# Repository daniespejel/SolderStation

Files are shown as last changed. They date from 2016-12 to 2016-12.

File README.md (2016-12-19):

# Solderstation

Barebones Atmega328 based Soldering station  
Firmware: https://github.com/fngstudios/SolderStation_Software

## Features  
*FTDI/Arduino programming port     
*Common soldering tip (with thermocouple) compatible  
*Uses MAX31856 for TC reading  
*Configurable TC type supports J,K,N,E,etc  
*Configurable LCD contrast  
*PID control Kp,Ki and Kd configurable via UI  
*Idle mode for longer tip life  
*Automatic switch-off  
*Arduino compatible 100% customizable  
*Uses any PSU up to 35v like common laptop PSUs (depends on your tip)  
*Can be used barebones (with no cabinet) or built inside custom cabinet  

## Images

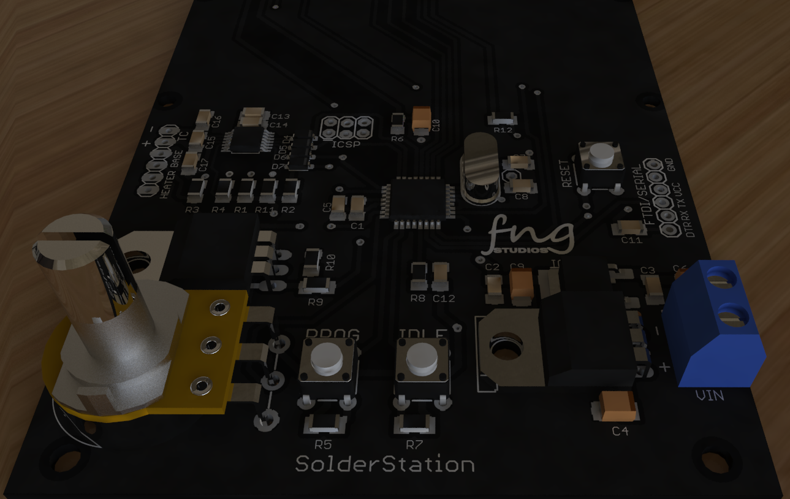
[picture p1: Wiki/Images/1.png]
  
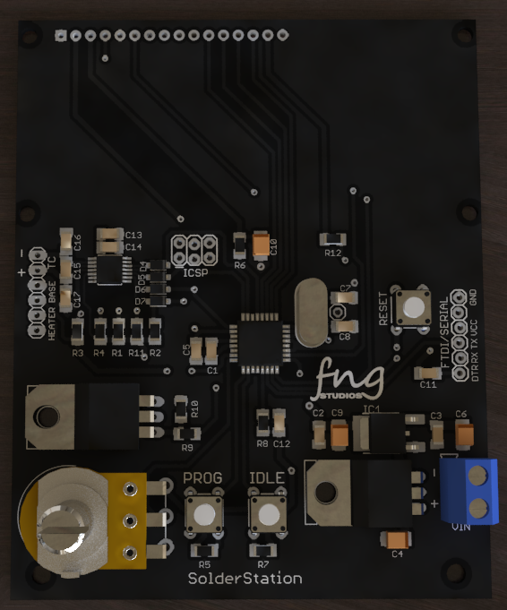
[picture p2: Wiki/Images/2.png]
  
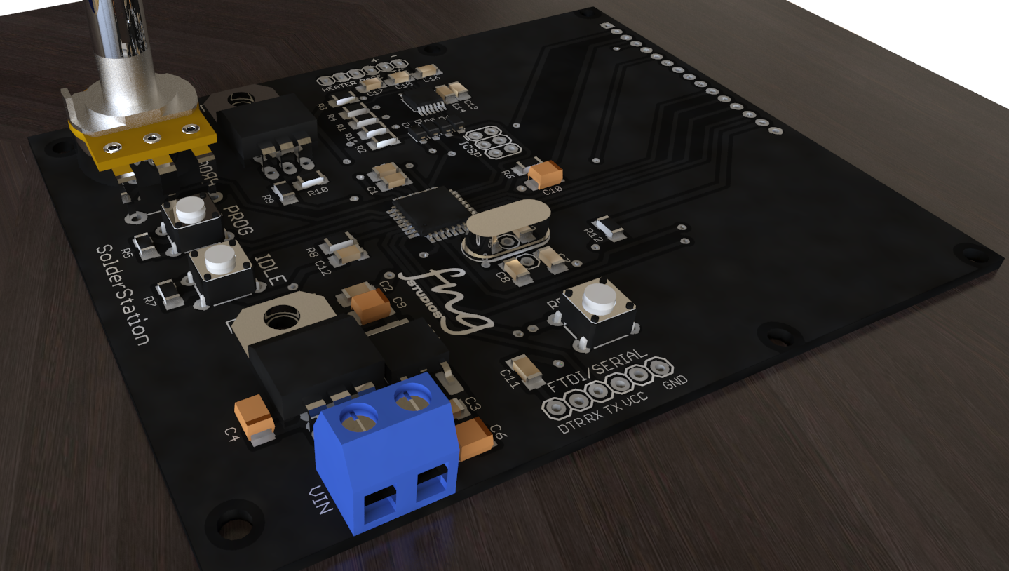
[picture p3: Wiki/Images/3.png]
  
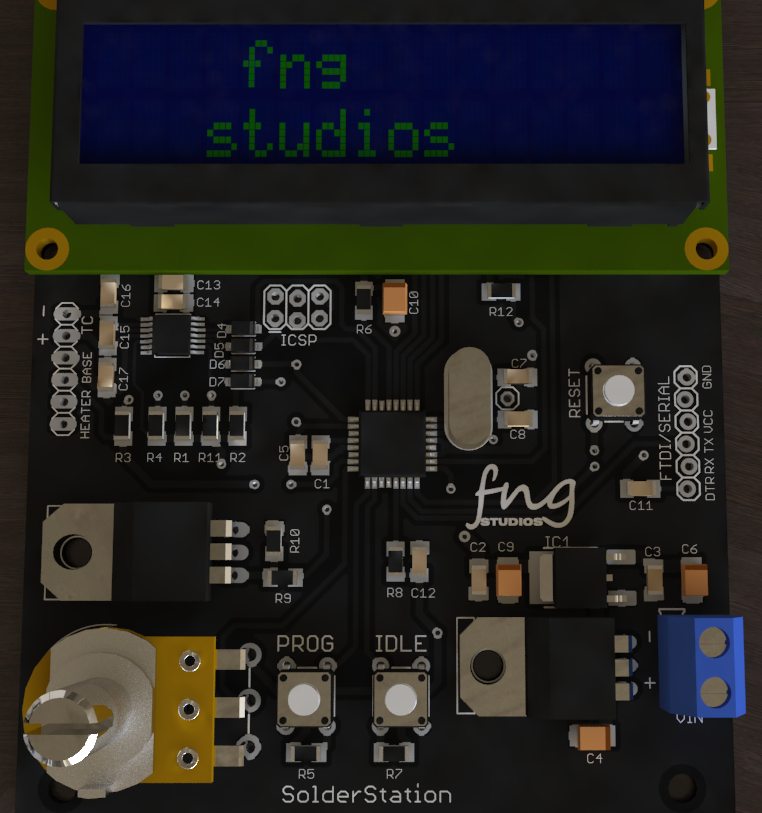
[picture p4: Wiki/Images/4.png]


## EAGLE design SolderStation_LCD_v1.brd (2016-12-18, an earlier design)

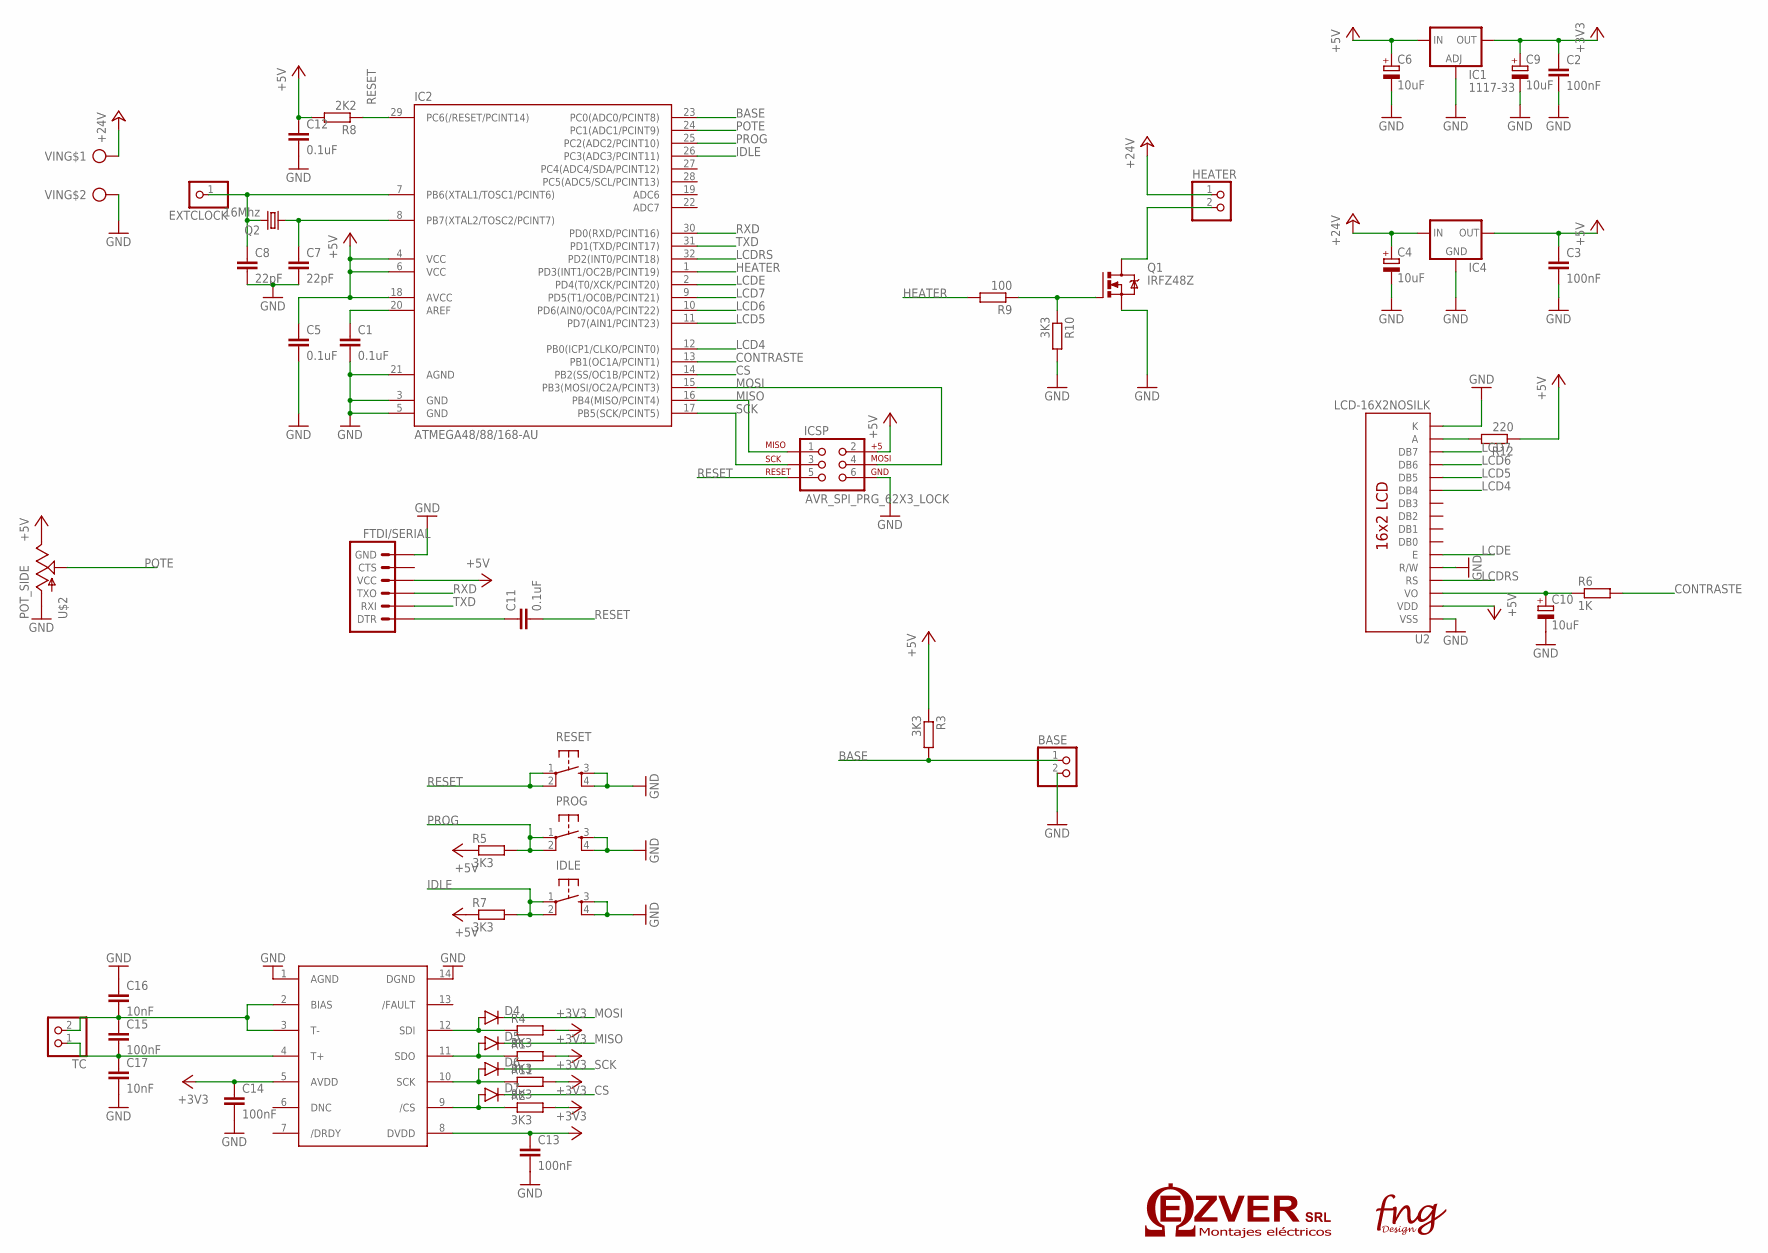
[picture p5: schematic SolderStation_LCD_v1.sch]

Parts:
BASE: PINHD-1X2; 1X02
C1, C5, C11, C12: 0.1uF; C1206K
C2, C3, C13, C14, C15: 100nF; C1206K
C4, C6, C9, C10: 10uF; CT3528
C7, C8: 22pF; C1206K
C16, C17: 10nF; C1206K
D4, D5, D6, D7: DIODESOD123; SOD-123
EXTCLOCK: PINHD-1X1; 1X01
FTDI/SERIAL: ARDUINO_SERIAL_PROGRAMLOCK; 1X06_LOCK
HEATER: PINHD-1X2; 1X02
IC1: 1117-33; DPACK
IC2: ATMEGA48/88/168-AU; TQFP32-08
IC4: 78XXL
ICSP: AVR_SPI_PRG_62X3_LOCK; 2X3_LOCK
IDLE: TAC_SWITCHPTH; TACTILE-PTH
PROG: TAC_SWITCHPTH; TACTILE-PTH
Q1: IRFZ48Z; TO220BH
Q2: 16Mhz; HC49U70
R1, R2, R3, R4, R5, R7, R10, R11: 3K3; M1206
R6: 1K; M1206
R8: 2K2; M1206
R9: 100; M1206
R12: 220; M1206
RESET: TAC_SWITCHPTH; TACTILE-PTH
TC: PINHD-1X2; 1X02
TC1: MAX31856; TSSOP-14
U2: LCD-16X2NOSILK; LCD-16X2_NOSILK
U$2: POT_SIDE; POT_ALPHA_SIDE
VIN: CON2

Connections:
+3V3: C2.1, C9.+, C13.1, C14.1, IC1.4 (OUT), R1.2, R2.2, R4.2, R11.2, TC1.5 (AVDD), TC1.8 (DVDD)
+5V: C3.1, C5.1, C6.+, C12.1, FTDI/SERIAL.4 (VCC), IC1.3 (IN), IC2.4 (VCC), IC2.6 (VCC), IC2.18 (AVCC), IC4.OUT, ICSP.2, R3.1, R5.1, R7.1, R8.2, R12.1, U2.2 (VDD), U$2.3 (E)
+24V: C4.+, HEATER.1, IC4.IN, VIN.1
BASE: BASE.1, IC2.23 (PC0(ADC0/PCINT8)), R3.2
CONTRASTE: IC2.13 (PB1(OC1A/PCINT1)), R6.2
CS: D7.C, IC2.14 (PB2(SS/OC1B/PCINT2))
GND: BASE.2, C1.2, C2.2, C3.2, C4.-, C5.2, C6.-, C7.2, C8.2, C9.-, C10.-, C12.2, C13.2, C14.2, C16.1, C17.2, FTDI/SERIAL.6 (GND), IC1.1 (ADJ), IC2.3 (GND), IC2.5 (GND), IC2.21 (AGND), IC4.GND, ICSP.6, IDLE.3, IDLE.4, PROG.3, PROG.4, Q1.S, R10.2, RESET.3, RESET.4, TC1.1 (AGND), TC1.14 (DGND), U2.1 (VSS), U2.5 (R/W), U2.16 (K), U$2.1 (A), VIN.2
HEATER: IC2.1 (PD3(INT1/OC2B/PCINT19)), R9.2
IDLE: IC2.26 (PC3(ADC3/PCINT11)), IDLE.1, IDLE.2, R7.2
LCD4: IC2.12 (PB0(ICP1/CLKO/PCINT0)), U2.11 (DB4)
LCD5: IC2.11 (PD7(AIN1/PCINT23)), U2.12 (DB5)
LCD6: IC2.10 (PD6(AIN0/OC0A/PCINT22)), U2.13 (DB6)
LCD7: IC2.9 (PD5(T1/OC0B/PCINT21)), U2.14 (DB7)
LCDE: IC2.2 (PD4(T0/XCK/PCINT20)), U2.6 (E)
LCDRS: IC2.32 (PD2(INT0/PCINT18)), U2.4 (RS)
MISO: D5.C, IC2.16 (PB4(MISO/PCINT4)), ICSP.1
MOSI: D4.C, IC2.15 (PB3(MOSI/OC2A/PCINT3)), ICSP.4
unnamed: Q1.G, R9.1, R10.1
unnamed: D7.A, R2.1, TC1.9 (/CS)
unnamed: D6.A, R11.1, TC1.10 (SCK)
unnamed: D5.A, R1.1, TC1.11 (SDO)
unnamed: HEATER.2, Q1.D
unnamed: D4.A, R4.1, TC1.12 (SDI)
unnamed: C7.1, IC2.8 (PB7(XTAL2/TOSC2/PCINT7)), Q2.1
unnamed: C10.+, R6.1, U2.3 (VO)
unnamed: C8.1, EXTCLOCK.1, IC2.7 (PB6(XTAL1/TOSC1/PCINT6)), Q2.2
unnamed: C1.1, IC2.20 (AREF)
unnamed: R12.2, U2.15 (A)
unnamed: C11.1, FTDI/SERIAL.1 (DTR)
unnamed: C15.2, C17.1, TC.1, TC1.4 (T+)
unnamed: C15.1, C16.2, TC.2, TC1.2 (BIAS), TC1.3 (T-)
POTE: IC2.24 (PC1(ADC1/PCINT9)), U$2.2 (S)
PROG: IC2.25 (PC2(ADC2/PCINT10)), PROG.1, PROG.2, R5.2
RESET: C11.2, IC2.29 (PC6(/RESET/PCINT14)), ICSP.5, R8.1, RESET.1, RESET.2
RXD: FTDI/SERIAL.3 (TXO), IC2.30 (PD0(RXD/PCINT16))
SCK: D6.C, IC2.17 (PB5(SCK/PCINT5)), ICSP.3
TXD: FTDI/SERIAL.2 (RXI), IC2.31 (PD1(TXD/PCINT17))

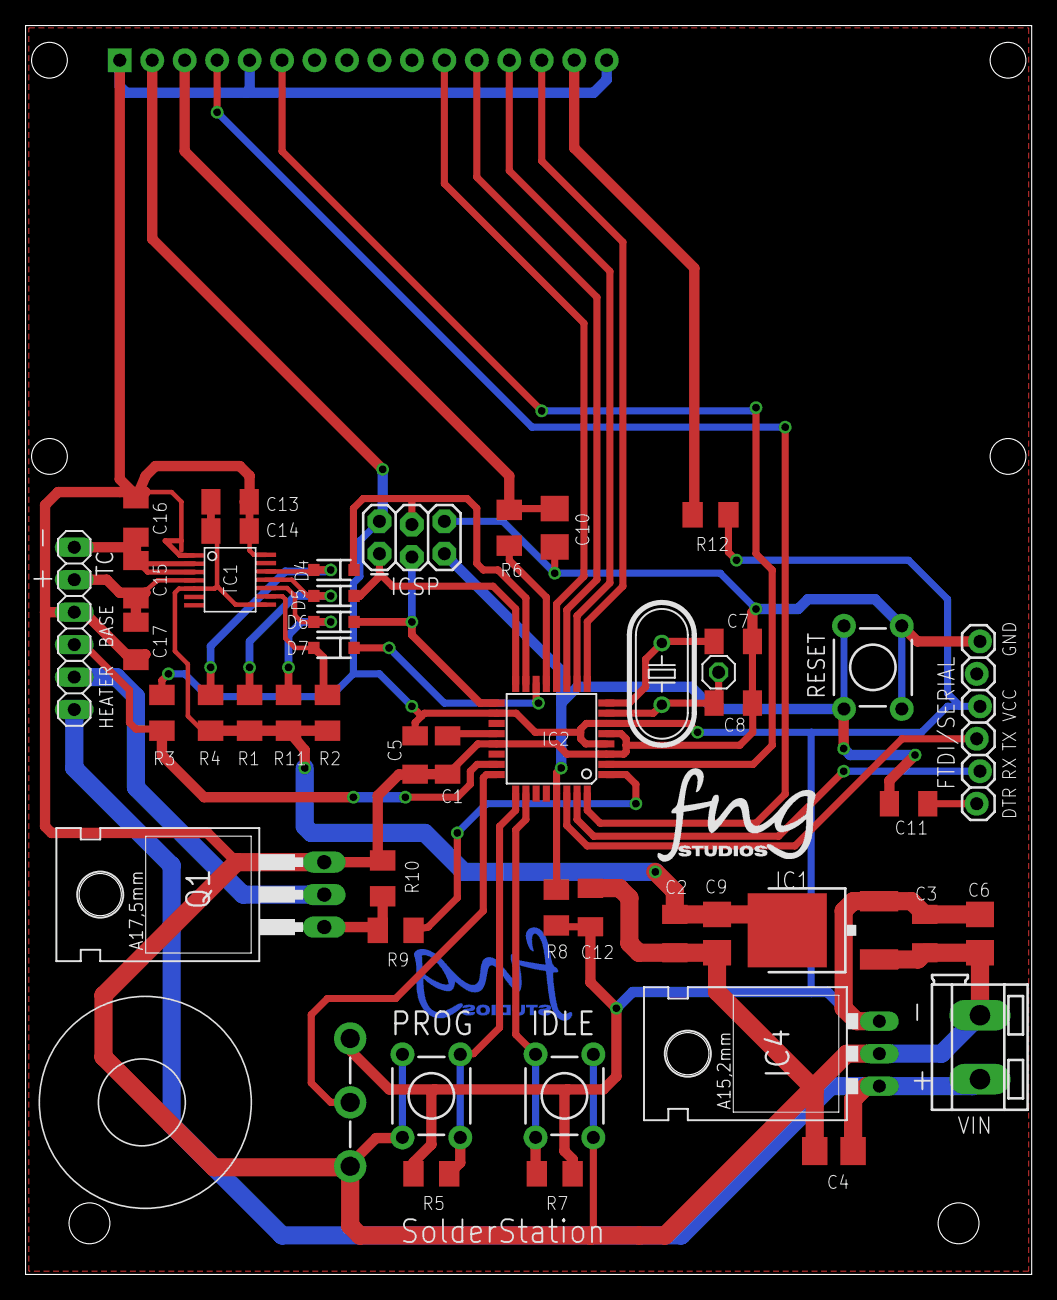
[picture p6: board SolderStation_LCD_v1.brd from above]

Board: 2 copper layers, 78.7 x 97.7 mm, 53 parts (1 on the bottom side), 37 nets.

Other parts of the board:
U$4: LOGOFNG
U$5: LOGOFNGNAME1

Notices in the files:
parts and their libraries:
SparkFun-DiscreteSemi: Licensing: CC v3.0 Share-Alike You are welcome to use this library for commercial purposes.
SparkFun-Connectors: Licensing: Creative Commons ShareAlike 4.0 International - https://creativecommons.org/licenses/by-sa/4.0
